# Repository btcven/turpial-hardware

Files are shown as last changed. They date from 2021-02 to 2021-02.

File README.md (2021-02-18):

# Turpial Hardware

Source files for Turpial hardware, designed using KiCAD v5.

## License

Copyright (C) 2021 Locha Mesh Developers

Licensed under the OHL-W-v2 Open Hardware license.

See [LICENSE](./LICENSE) for more information.

## The PCB Stack

According to the recomendations of Texas Instruments the stack will be a 4 layers sandwitch containing:

table-stack

### Layers, view and dimensions
section-stack

### Vias, view and dimensions

section-vias

## Plugins and Tools

### Required

#### RF Tools _KICAD PLUGIN_
    URL: https://github.com/easyw/RF-tools-KiCAD

####  Teardrops
    URL: https://github.com/NilujePerchut/kicad_scripts

### Optionals

#### INTERACTIVE BOM _KICAD PLUGIN_
    Description: Generate an interactive html Bill Of Materials (BOM)
    URL: https://github.com/openscopeproject/InteractiveHtmlBom
    
#### GRAPHICAL SYMBOL GENERATOR (KiSymGen) _KICAD PLUGIN_
    Description: KiSymGen is a graphical symbol generator which makes this process visual and less painful.
    URL: https://github.com/pixellon/imgui
    
#### library.io _ONLINE_TOOL_
    Description: Instantly generate PCB packages by entering a few dimensions from a data sheet.
    URL: https://library.io/

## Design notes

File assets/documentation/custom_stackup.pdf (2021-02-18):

| Layer Name | Usage | Copper Weight (oz) | Copper Thickness ( mils ) | Dielectric Thickness ( mils ) | Single/Diff pair (ohm) | | Tolorance | Single Width (mils) | Diff (90) width / Space(mil) | Diff (100) width / Space(mil)
| | Solder Mask | | 1
1 | TOP | Signal | 1 | 1.35 | | 50/90/100 | +/- | 10% | 6 | 8/5 | 8/7.5
| | Substrate | | | 7
2 | GND | Plane | 1 | 1.35
| | Substrate | | | 42
3 | PWR | Plane | 1 | 1.35
| | Substrate | | | 7
4 | BOTTOM | Signal | 1 | 1.35 | | 50/90/100 | +/- | 10% | 6 | 8/5 | 8/7.5
| | Solder Mask | | 1

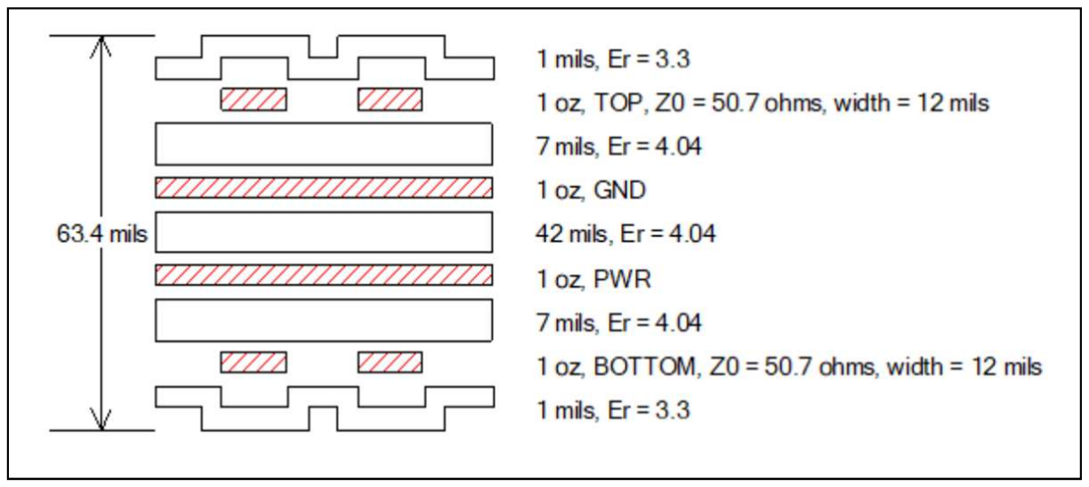
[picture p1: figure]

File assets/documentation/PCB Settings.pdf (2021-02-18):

# PCB Settings

Parámetros

Alto (H) | 156 | mm
Ancho (L) | 120 | mm
Grosor | 1,60 | mm
Nº Capas | 4 | --
Material | FR-4 tg170 | --
Vias | Tenting Vias | --
Surface finish | Immersion Gold | --
Immersion Gold Thickness | 1,00 | mils
Drill Size | <= 0,25 | mm

Distribución del stack, impedancia y tolerancias.

Copper
Weight
(oz)

## Copper Thickness ( mils )

## Dielectric Thickness ( mils )

## Single/Diff

| | | | | pair (ohm) | | Tole rance

## Single Width (mils)

## Diff (90) width / Space(mil)

| | | | | | | | | | Diff (100)
| | | | | | | | | | width /
| | | | | | | | | | Space(mil)
| | Solder M ask | | 1
1 | TOP | Signal | 1 | 1.35 | 50/90/100 | +/- | 10% | 6 | 8/5 | 8/7.5
Substrate | 7
2 | G N D | Plane | 1 | 1.35
Substrate | 42
3 | PW R | Plane | 1 | 1.35
Substrate | 7
4 | B OT T OM | Signal | 1 | 1.35 | 50/90/100 | +/- | 10% | 6 | 8/5 | 8/7.5
| | Solder M ask | | 1
Layer Name | Usage

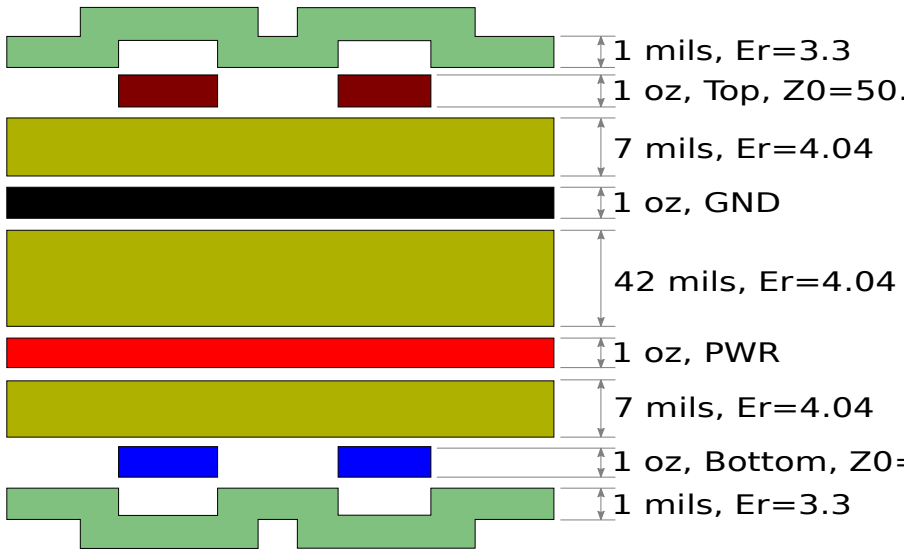
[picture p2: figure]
1 oz, PWR; 1 oz, GND; 42 mils, Er=4.04; 7 mils, Er=4.04; 1 mils, Er=3.3

1 oz, Top, Z0=50.7 Ohms, width=12 mils

1 oz, Bottom, Z0=50.7 Ohms, width=12 mils

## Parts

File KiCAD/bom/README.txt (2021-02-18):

- SM: Surface Mount
- TH:Through Hole.
- DNI: Do Not Include.
- DNM: Include the component in the budget but don't mount it
- DNI-915: Do Not Include for 915MHz

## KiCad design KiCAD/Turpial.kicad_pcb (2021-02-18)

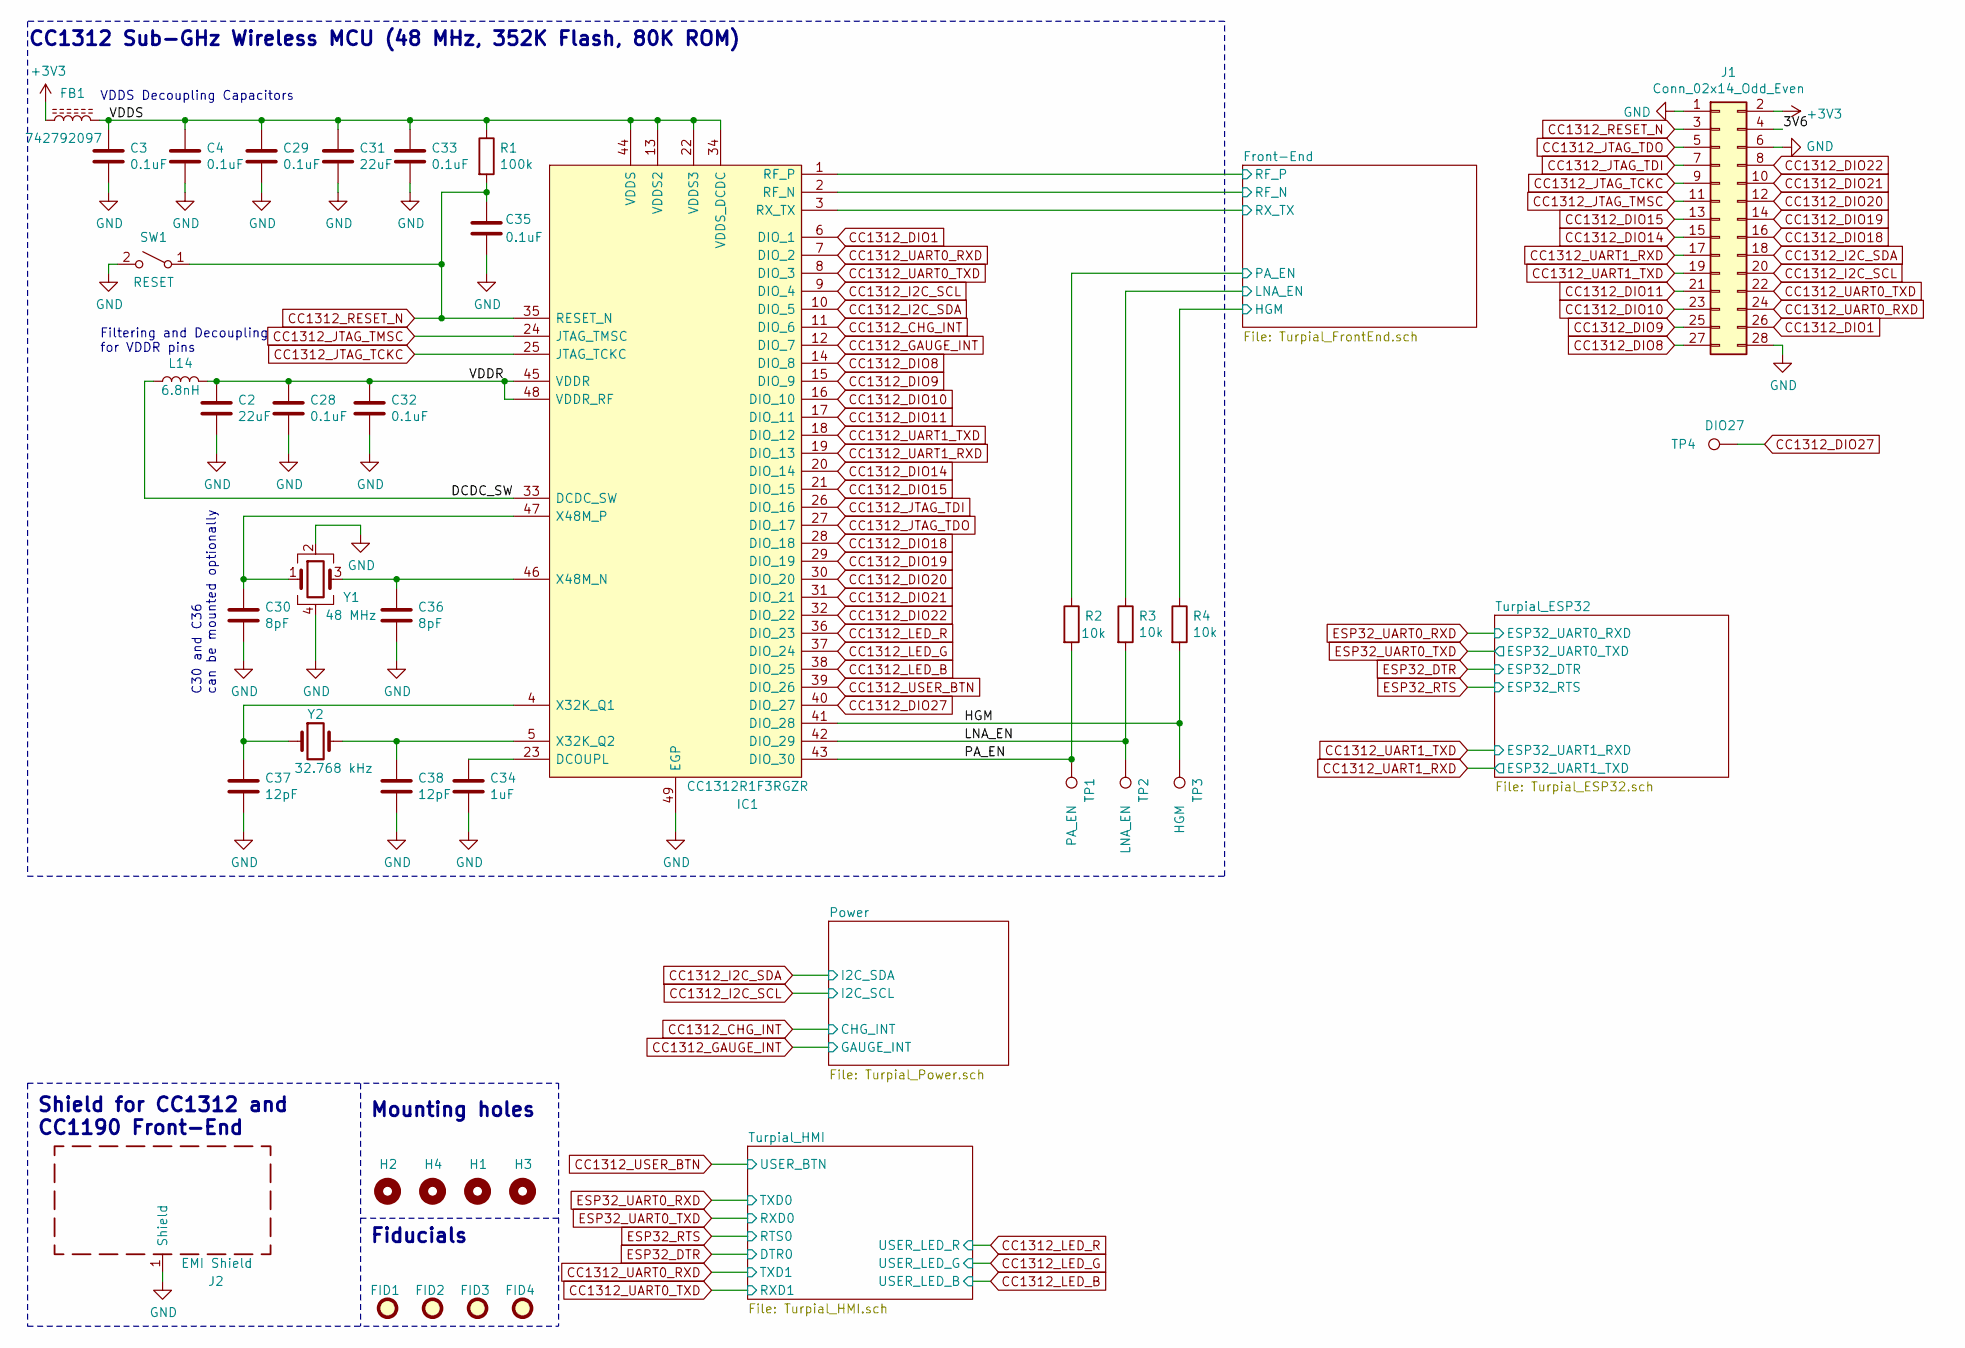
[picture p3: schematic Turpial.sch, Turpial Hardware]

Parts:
C2, C31: 22uF; C_0805_2012Metric; Manufacturer_Part_Number GRM21BR61E226ME44L; Mouser Part Number 81-GRM21BR61E226ME4L
C3, C4, C28, C29, C32, C33, C35: 0.1uF; C_0402_1005Metric; Manufacturer_Part_Number GRM155R61H104KE19D; Mouser Part Number 81-GRM155R61H104KE9D
C30, C36: 8pF; C_0402_1005Metric; Manufacturer_Part_Number GRM0225C1E8R0WA03L; Mouser Part Number 81-GRM0225C1E8R0WA3L
C34: 1uF; C_0402_1005Metric; Manufacturer_Part_Number GRM155R61E105KA12D; Mouser Part Number 81-GRM155R61E105KA2D
C37, C38: 12pF; C_0402_1005Metric; Manufacturer_Part_Number GJM1555C1H120JB01D; Mouser Part Number 81-GJM1555C1H120JB1D
FB1: 742792097; L_0805_2012Metric; Manufacturer_Part_Number 742792097; Mouser Part Number 710-742792097
FID1, FID2, FID3, FID4: Fiducial; Fiducial_1mm_Mask2mm
H1, H2, H3, H4: MountingHole; MountingHole_2.5mm_Pad_Via
IC1: CC1312R1F3RGZR; Texas_S-PVQFN-N48_EP5.15x5.15mm_ThermalVias; Manufacturer_Part_Number CC1312R1F3RGZR; Mouser Part Number 595-CC1312R1F3RGZR
J1: Conn_02x14_Odd_Even; PinHeader_2x14_P2.54mm_Vertical_SMD; Manufacturer_Part_Number 15-91-2140; Mouser Part Number 538-15-91-2140
J2: EMI Shield; SMS-461-F; Manufacturer_Part_Number SMS-461F; Mouser Part Number 861-SMS-461F
L14: 6.8nH; L_0805_2012Metric; Manufacturer_Part_Number MLZ2012N6R8LT000; Mouser Part Number 810-MLZ2012N6R8LT000
R1: 100k; R_0402_1005Metric; Manufacturer_Part_Number RC0402FR-7D100KL; Mouser Part Number 603-RC0402FR-7D100KL
R2, R3, R4: 10k; R_0402_1005Metric; Manufacturer_Part_Number RC0402FR-0710KL; Mouser Part Number 603-RC0402FR-0710KL
SW1: RESET; WS-TASU-Series
TP1: PA_EN; TestPoint_Pad_D1.0mm
TP2: LNA_EN; TestPoint_Pad_D1.0mm
TP3: HGM; TestPoint_Pad_D1.0mm
TP4: DIO27; TestPoint_Pad_D1.0mm
Y1: 48 MHz; Crystal_SMD_2016-4Pin_2.0x1.6mm; Manufacturer_Part_Number NX2016SA-48M-EXS00A-CS08718; Mouser Part Number 344-NX2016SA48S08718
Y2: 32.768 kHz; Crystal_SMD_3215-2Pin_3.2x1.5mm; Manufacturer_Part_Number FC-135 32.7680KA-A3; Mouser Part Number 732-FC135-32.76KAA3

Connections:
+3V3: FB1.1, J1.2; also elsewhere on the board
/3V6: J1.4
/DCDC_SW: IC1.33 (DCDC_SW), L14.1
/Front-End/HGM: R4.1; also elsewhere on the board
/Front-End/LNA_EN: R3.1; also elsewhere on the board
/Front-End/PA_EN: R2.1; also elsewhere on the board
/Front-End/RF_N: IC1.2 (RF_N); also elsewhere on the board
/Front-End/RF_P: IC1.1 (RF_P); also elsewhere on the board
/Front-End/RX_TX: IC1.3 (RX_TX); also elsewhere on the board
/HGM: IC1.41 (DIO_28), R4.2, TP3.1
/LNA_EN: IC1.42 (DIO_29), R3.2, TP2.1
/PA_EN: IC1.43 (DIO_30), R2.2, TP1.1
/VDDR: C2.1, C28.1, C32.1, IC1.45 (VDDR), IC1.48 (VDDR_RF), L14.2
/VDDS: C3.1, C4.1, C29.1, C31.1, C33.1, FB1.2, IC1.13 (VDDS2), IC1.22 (VDDS3), IC1.34 (VDDS_DCDC), IC1.44 (VDDS), R1.1
CC1312_CHG_INT: IC1.11 (DIO_6); also elsewhere on the board
CC1312_DIO1: IC1.6 (DIO_1), J1.26
CC1312_DIO8: IC1.14 (DIO_8), J1.27
CC1312_DIO9: IC1.15 (DIO_9), J1.25
CC1312_DIO10: IC1.16 (DIO_10), J1.23
CC1312_DIO11: IC1.17 (DIO_11), J1.21
CC1312_DIO14: IC1.20 (DIO_14), J1.15
CC1312_DIO15: IC1.21 (DIO_15), J1.13
CC1312_DIO18: IC1.28 (DIO_18), J1.16
CC1312_DIO19: IC1.29 (DIO_19), J1.14
CC1312_DIO20: IC1.30 (DIO_20), J1.12
CC1312_DIO21: IC1.31 (DIO_21), J1.10
CC1312_DIO22: IC1.32 (DIO_22), J1.8
CC1312_DIO27: IC1.40 (DIO_27), TP4.1
CC1312_GAUGE_INT: IC1.12 (DIO_7); also elsewhere on the board
CC1312_I2C_SCL: IC1.9 (DIO_4), J1.20; also elsewhere on the board
CC1312_I2C_SDA: IC1.10 (DIO_5), J1.18; also elsewhere on the board
CC1312_JTAG_TCKC: IC1.25 (JTAG_TCKC), J1.9
CC1312_JTAG_TDI: IC1.26 (DIO_16), J1.7
CC1312_JTAG_TDO: IC1.27 (DIO_17), J1.5
CC1312_JTAG_TMSC: IC1.24 (JTAG_TMSC), J1.11
CC1312_LED_B: IC1.38 (DIO_25); also elsewhere on the board
CC1312_LED_G: IC1.37 (DIO_24); also elsewhere on the board
CC1312_LED_R: IC1.36 (DIO_23); also elsewhere on the board
CC1312_RESET_N: C35.1, IC1.35 (RESET_N), J1.3, R1.2, SW1.1 (A)
CC1312_UART0_RXD: IC1.7 (DIO_2), J1.24; also elsewhere on the board
CC1312_UART0_TXD: IC1.8 (DIO_3), J1.22; also elsewhere on the board
CC1312_UART1_RXD: IC1.19 (DIO_13), J1.17; also elsewhere on the board
CC1312_UART1_TXD: IC1.18 (DIO_12), J1.19; also elsewhere on the board
CC1312_USER_BTN: IC1.39 (DIO_26); also elsewhere on the board
GND: C2.2, C3.2, C4.2, C28.2, C29.2, C30.2, C31.2, C32.2, C33.2, C34.2, C35.2, C36.2, C37.2, C38.2, IC1.49 (EGP), J1.1, J1.6, J1.28, J2.1, SW1.2 (B), Y1.2, Y1.4; also elsewhere on the board
unnamed: C30.1, IC1.47 (X48M_P), Y1.1
unnamed: C34.1, IC1.23 (DCOUPL)
unnamed: C36.1, IC1.46 (X48M_N), Y1.3
unnamed: C37.1, IC1.4 (X32K_Q1), Y2.1
unnamed: C38.1, IC1.5 (X32K_Q2), Y2.2

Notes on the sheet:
VDDS Decoupling Capacitors
Filtering and Decoupling for VDDR pins
C30 and C36 can be mounted optionally
CC1312 Sub-GHz Wireless MCU (48 MHz, 352K Flash, 80K ROM)
Shield for CC1312 and CC1190 Front-End
Fiducials
Mounting holes

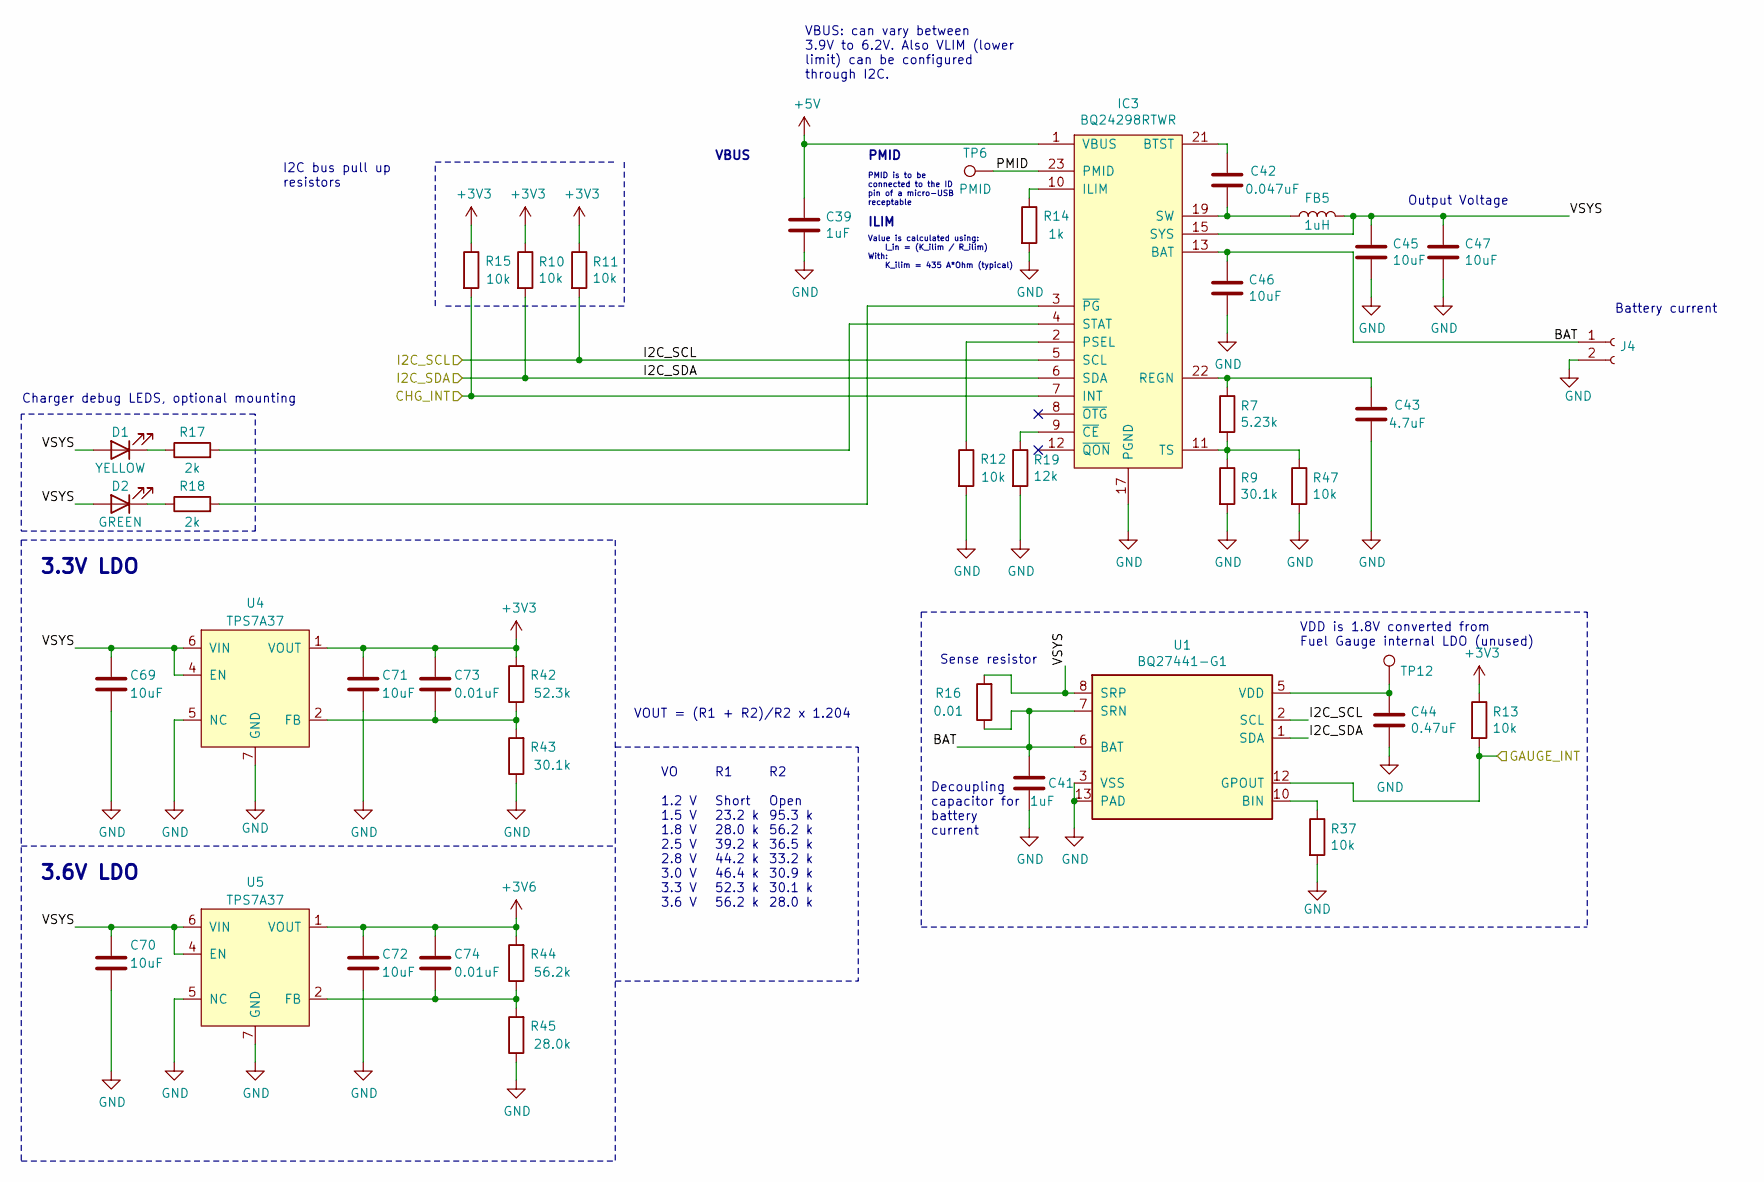
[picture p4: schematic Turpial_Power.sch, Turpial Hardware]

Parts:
C39, C41: 1uF; C_0402_1005Metric; Manufacturer_Part_Number GRM155R61E105KA12D; Mouser Part Number 81-GRM155R61E105KA2D
C42: 0.047uF; C_0402_1005Metric; Manufacturer_Part_Number GRM155R71H473KE14D; Mouser Part Number 81-GRM155R71H473KE4D
C43: 4.7uF; C_0402_1005Metric; Manufacturer_Part_Number GRM155R61A475MEAAD; Mouser Part Number 81-GRM155R61A475MEAD
C44: 0.47uF; C_0402_1005Metric; Manufacturer_Part_Number GRM155R71A474KE01D; Mouser Part Number 81-GRM155R71A474KE1D
C45, C46, C47, C69, C70, C71, C72: 10uF; C_0603_1608Metric; Manufacturer_Part_Number GRM188R61E106MA73J; Mouser Part Number 81-GRM188R61E106MA3J
C73, C74: 0.01uF; C_0603_1608Metric; Manufacturer_Part_Number GRM188R72A103KA01D; Mouser Part Number 81-GRM188R72A103KA1D
D1: YELLOW; LED_0603_1608Metric; Manufacturer_Part_Number LTST-C191KRKT; Mouser Part Number 859-LTST-C191KRKT
D2: GREEN; LED_0603_1608Metric; Manufacturer_Part_Number LTST-C191KGKT; Mouser Part Number 859-LTST-C191KGKT
FB5: 1uH; L_0805_2012Metric; Manufacturer_Part_Number DFE201210S-1R0M=P2; Mouser Part Number 81-DFE201210S-1R0MP2
IC3: BQ24298RTWR; Texas_S-PWQFN-N24_EP2.7x2.7mm_ThermalVias; Manufacturer_Part_Number BQ24298RTWR; Mouser Part Number 595-BQ24298RTWR
J4: Conn_01x02_Female; PinHeader_1x02_P2.54mm_Vertical
R7: 5.23k; R_0402_1005Metric; Manufacturer_Part_Number RC0402FR-075K23L; Mouser Part Number 603-RC0402FR-075K23L
R9, R43: 30.1k; R_0603_1608Metric; Manufacturer_Part_Number RC0603FR-0730K1L; Mouser Part Number 603-RC0603FR-0730K1L
R10, R11, R12, R13, R15, R37, R47: 10k; R_0402_1005Metric; Manufacturer_Part_Number RC0402FR-0710KL; Mouser Part Number 603-RC0402FR-0710KL
R14: 1k; R_0603_1608Metric; Manufacturer_Part_Number RC0603FR-071KL; Mouser Part Number 603-RC0603FR-071KL
R16: 0.01; R_0603_1608Metric; Manufacturer_Part_Number MFC0603-R01FT5; Mouser Part Number 756-MFC0603-R01FT5
R17, R18: 2k; R_0402_1005Metric; Manufacturer_Part_Number RC0402FR-072KL; Mouser Part Number 603-RC0402FR-072KL
R19: 12k; R_0402_1005Metric; Manufacturer_Part_Number RC0402FR-0712KL; Mouser Part Number 603-RC0402FR-0712KL
R42: 52.3k; R_0603_1608Metric; Manufacturer_Part_Number RC0603FR-0752K3L; Mouser Part Number 603-RC0603FR-0752K3L
R44: 56.2k; R_0603_1608Metric; Manufacturer_Part_Number RC0603FR-0756K2L; Mouser Part Number 603-RC0603FR-0756K2L
R45: 28.0k; R_0603_1608Metric; Manufacturer_Part_Number RC0603FR-0728KL; Mouser Part Number 603-RC0603FR-0728KL
TP6: PMID; TestPoint_Pad_D1.0mm
TP12: TestPoint; TestPoint_Pad_D1.0mm
U1: BQ27441-G1; Texas_S-PDSO-N12; Manufacturer_Part_Number BQ27441DRZT-G1A; Mouser Part Number 595-BQ27441DRZT-G1A
U4, U5: TPS7A37; Manufacturer_Part_Number TPS7A3701DRVR; Mouser Part Number 595-TPS7A3701DRVR

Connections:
+3V3: C71.1, C73.1, R10.1, R11.1, R13.1, R15.1, R42.2, U4.1 (VOUT); also elsewhere on the board
+3V6: C72.1, C74.1, R44.2, U5.1 (VOUT); also elsewhere on the board
+5V: C39.1, IC3.1 (VBUS), IC3.24 (VBUS); also elsewhere on the board
/Power/BAT: C41.1, C46.2, IC3.13 (BAT), IC3.14 (BAT), J4.1, R16.1, U1.6 (BAT), U1.7 (SRN)
/Power/PMID: IC3.23 (PMID), TP6.1
/Power/VSYS: C45.1, C47.1, C69.1, C70.1, D1.2 (A), D2.2 (A), FB5.2, IC3.15 (SYS), IC3.16 (SYS), R16.2, U1.8 (SRP), U4.4 (EN), U4.6 (VIN), U5.4 (EN), U5.6 (VIN)
CC1312_CHG_INT: IC3.7 (INT), R15.2; also elsewhere on the board
CC1312_GAUGE_INT: R13.2, U1.12 (GPOUT); also elsewhere on the board
CC1312_I2C_SCL: IC3.5 (SCL), R11.2, U1.2 (SCL); also elsewhere on the board
CC1312_I2C_SDA: IC3.6 (SDA), R10.2, U1.1 (SDA); also elsewhere on the board
GND: C39.2, C41.2, C43.2, C44.2, C45.2, C46.1, C47.2, C69.2, C70.2, C71.2, C72.2, IC3.17 (PGND), IC3.18 (PGND), IC3.25 (GND), J4.2, R9.2, R12.2, R14.2, R19.2, R37.2, R43.1, R45.1, R47.2, U1.3 (VSS), U1.13 (PAD), U4.3 (GND), U4.5 (NC), U4.7 (GND), U5.3 (GND), U5.5 (NC), U5.7 (GND); also elsewhere on the board
unnamed: C42.1, FB5.1, IC3.19 (SW), IC3.20 (SW)
unnamed: C42.2, IC3.21 (BTST)
unnamed: C43.1, IC3.22 (REGN), R7.1
unnamed: C44.1, TP12.1, U1.5 (VDD)
unnamed: C73.2, R42.1, R43.2, U4.2 (FB)
unnamed: C74.2, R44.1, R45.2, U5.2 (FB)
unnamed: D1.1 (K), R17.1
unnamed: D2.1 (K), R18.1
unnamed: IC3.2 (PSEL), R12.1
unnamed: IC3.3 (~PG), R18.2
unnamed: IC3.4 (STAT), R17.2
unnamed: IC3.9 (~CE), R19.1
unnamed: IC3.10 (ILIM), R14.1
unnamed: IC3.11 (TS), R7.2, R9.1, R47.1
unnamed: R37.1, U1.10 (BIN)

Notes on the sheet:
VBUS: can vary between 3.9V to 6.2V. Also VLIM (lower limit) can be configured through I2C.
ILIM
3.3V LDO
3.6V LDO
VOUT = (R1 + R2)/R2 x 1.204
R1 Short 23.2 k 28.0 k 39.2 k 44.2 k 46.4 k 52.3 k 56.2 k
R2 Open 95.3 k 56.2 k 36.5 k 33.2 k 30.9 k 30.1 k 28.0 k
Charger debug LEDS, optional mounting
VDD is 1.8V converted from Fuel Gauge internal LDO (unused)
Sense resistor
Decoupling capacitor for battery current
I2C bus pull up resistors
Output Voltage
PMID
VO 1.2 V 1.5 V 1.8 V 2.5 V 2.8 V 3.0 V 3.3 V 3.6 V
Battery current
Value is calculated using: I_in = (K_ilim / R_ilim) With: K_ilim = 435 A*Ohm (typical)
VBUS
PMID is to be connected to the ID pin of a micro-USB receptable

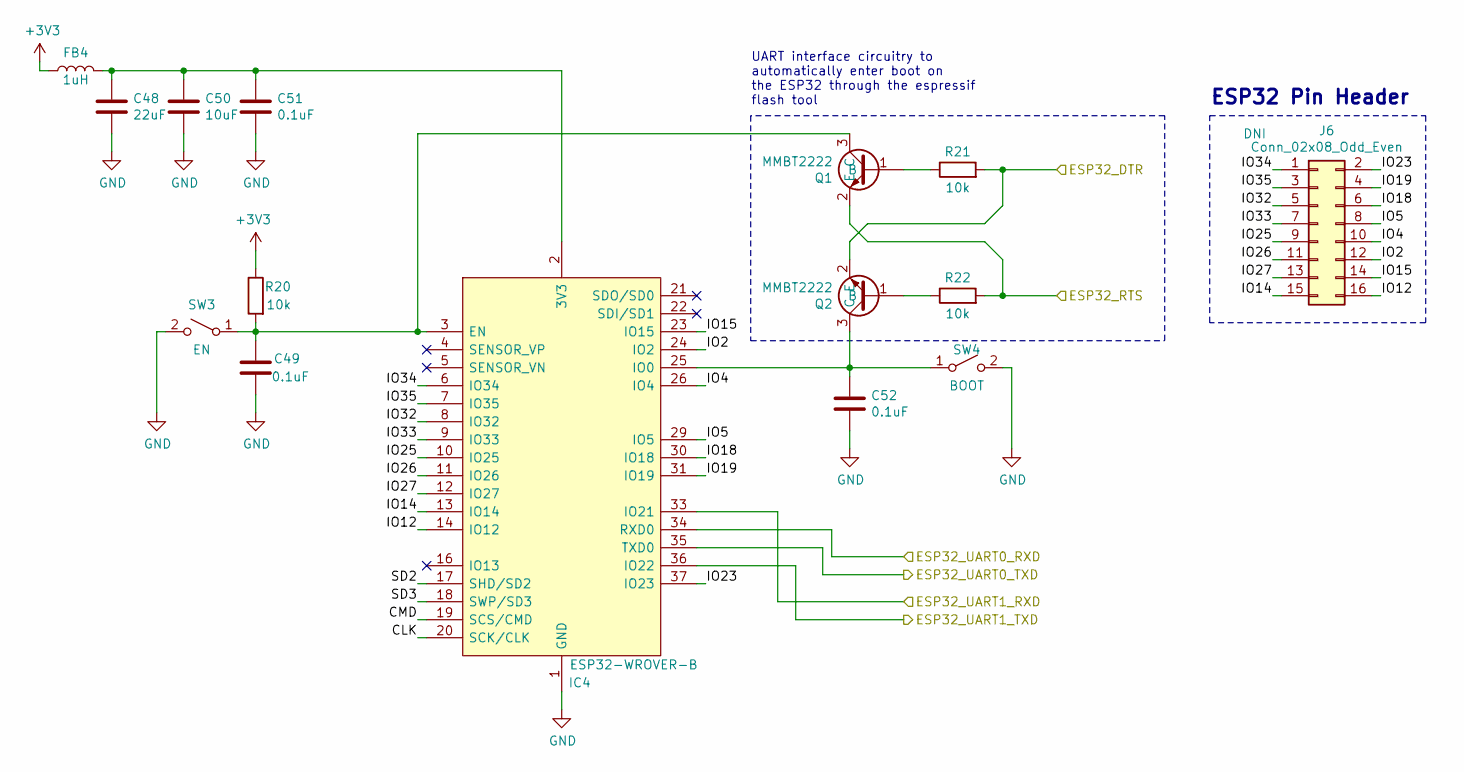
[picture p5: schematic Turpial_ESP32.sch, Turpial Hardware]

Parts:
C48: 22uF; C_0805_2012Metric; Manufacturer_Part_Number GRM21BR61E226ME44L; Mouser Part Number 81-GRM21BR61E226ME4L
C49, C51, C52: 0.1uF; C_0402_1005Metric; Manufacturer_Part_Number GRM155R61H104KE19D; Mouser Part Number 81-GRM155R61H104KE9D
C50: 10uF; C_0603_1608Metric; Manufacturer_Part_Number GRM188R61E106MA73J; Mouser Part Number 81-GRM188R61E106MA3J
FB4: 1uH; L_0805_2012Metric; Manufacturer_Part_Number DFE201210S-1R0M=P2; Mouser Part Number 81-DFE201210S-1R0MP2
IC4: ESP32-WROVER-B; Manufacturer_Part_Number ESP32-WROVER-B(M213DH3264PH3Q0); Mouser Part Number 356-ESP32-WROVER-B
J6: Conn_02x08_Odd_Even; PinHeader_2x08_P2.54mm_Vertical_SMD; Manufacturer_Part_Number 71308-5408; Mouser Part Number 538-71308-5408
Q1, Q2: MMBT2222; SOT-23; Manufacturer_Part_Number MMBT2222ALT1G; Mouser Part Number 863-MMBT2222ALT1G
R20, R21, R22: 10k; R_0402_1005Metric; Manufacturer_Part_Number RC0402FR-0710KL; Mouser Part Number 603-RC0402FR-0710KL
SW3: EN; WS-TASU-Series
SW4: BOOT; WS-TASU-Series

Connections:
+3V3: FB4.1, R20.1; also elsewhere on the board
/Turpial_ESP32/CLK: IC4.20 (SCK/CLK)
/Turpial_ESP32/CMD: IC4.19 (SCS/CMD)
/Turpial_ESP32/IO2: IC4.24 (IO2), J6.12
/Turpial_ESP32/IO4: IC4.26 (IO4), J6.10
/Turpial_ESP32/IO5: IC4.29 (IO5), J6.8
/Turpial_ESP32/IO12: IC4.14 (IO12), J6.16
/Turpial_ESP32/IO14: IC4.13 (IO14), J6.15
/Turpial_ESP32/IO15: IC4.23 (IO15), J6.14
/Turpial_ESP32/IO18: IC4.30 (IO18), J6.6
/Turpial_ESP32/IO19: IC4.31 (IO19), J6.4
/Turpial_ESP32/IO23: IC4.37 (IO23), J6.2
/Turpial_ESP32/IO25: IC4.10 (IO25), J6.9
/Turpial_ESP32/IO26: IC4.11 (IO26), J6.11
/Turpial_ESP32/IO27: IC4.12 (IO27), J6.13
/Turpial_ESP32/IO32: IC4.8 (IO32), J6.5
/Turpial_ESP32/IO33: IC4.9 (IO33), J6.7
/Turpial_ESP32/IO34: IC4.6 (IO34), J6.1
/Turpial_ESP32/IO35: IC4.7 (IO35), J6.3
/Turpial_ESP32/SD2: IC4.17 (SHD/SD2)
/Turpial_ESP32/SD3: IC4.18 (SWP/SD3)
CC1312_UART1_RXD: IC4.36 (IO22); also elsewhere on the board
CC1312_UART1_TXD: IC4.33 (IO21); also elsewhere on the board
ESP32_DTR: Q2.2 (E), R21.2; also elsewhere on the board
ESP32_RTS: Q1.2 (E), R22.2; also elsewhere on the board
ESP32_UART0_RXD: IC4.34 (RXD0); also elsewhere on the board
ESP32_UART0_TXD: IC4.35 (TXD0); also elsewhere on the board
GND: C48.2, C49.2, C50.2, C51.2, C52.2, IC4.1 (GND), IC4.15 (GND), IC4.38 (GND), IC4.39 (GND), SW3.2 (B), SW4.2 (B); also elsewhere on the board
unnamed: C48.1, C50.1, C51.1, FB4.2, IC4.2 (3V3)
unnamed: C49.1, IC4.3 (EN), Q1.3 (C), R20.2, SW3.1 (A)
unnamed: C52.1, IC4.25 (IO0), Q2.3 (C), SW4.1 (A)
unnamed: Q1.1 (B), R21.1
unnamed: Q2.1 (B), R22.1

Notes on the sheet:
UART interface circuitry to automatically enter boot on the ESP32 through the espressif flash tool
ESP32 Pin Header

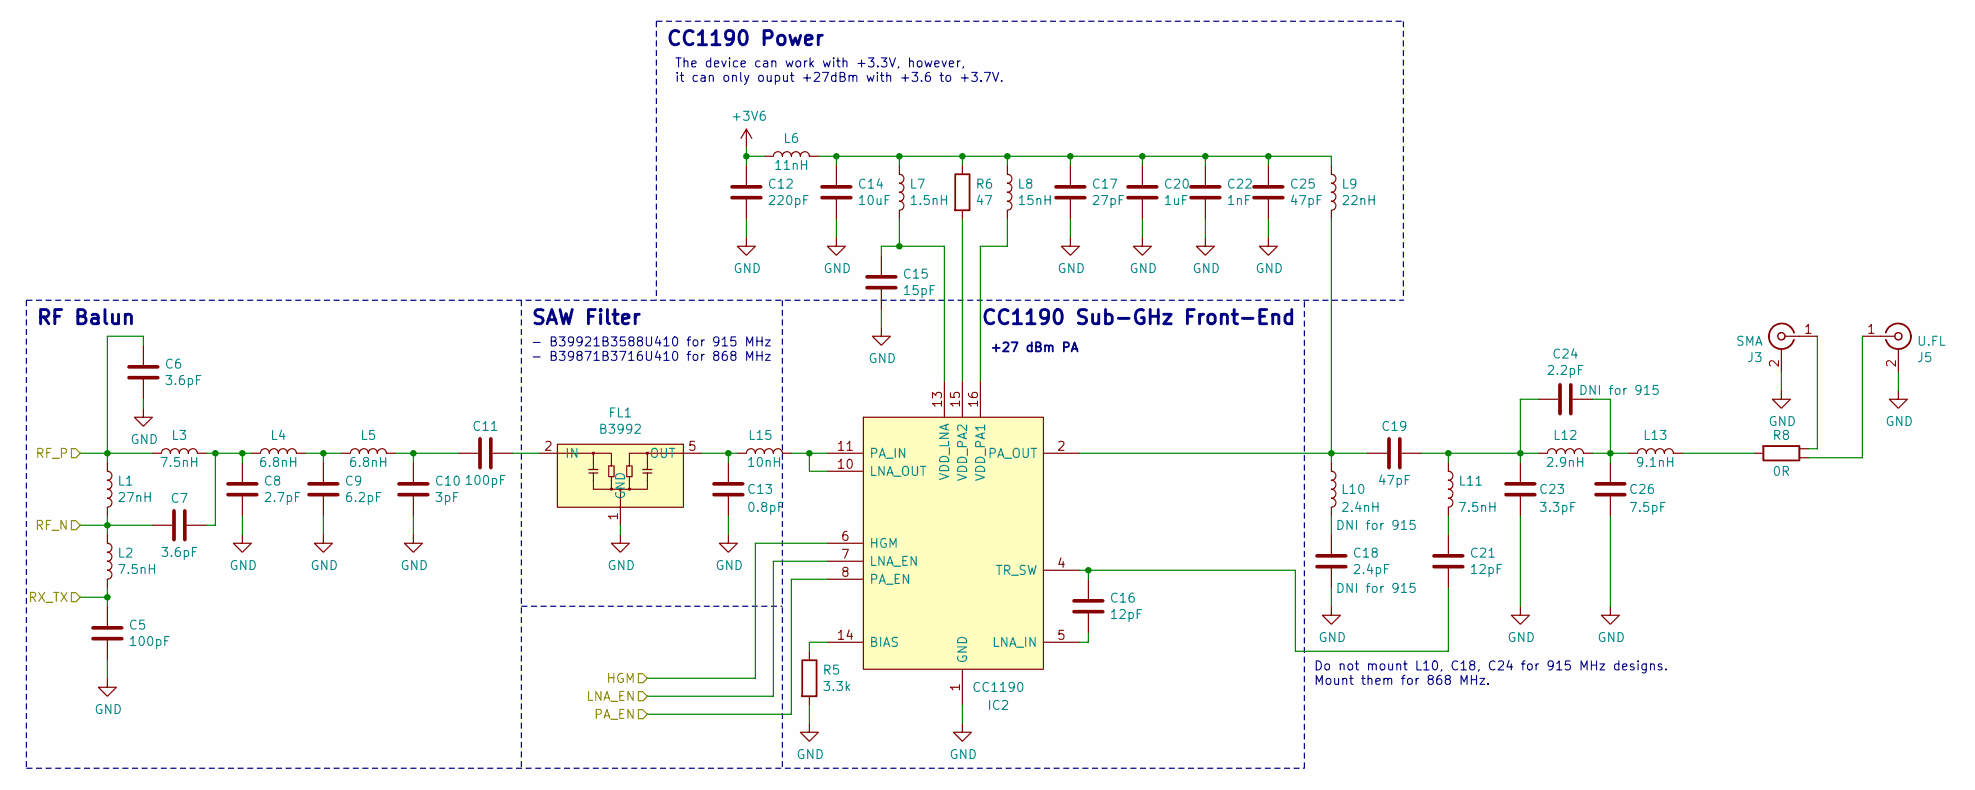
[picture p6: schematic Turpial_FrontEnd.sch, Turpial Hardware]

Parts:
C5, C11: 100pF; C_0402_1005Metric; Manufacturer_Part_Number GCM1555C1H101JA16D; Mouser Part Number 81-GCM1555C1H101JA6D
C6, C7: 3.6pF; C_0402_1005Metric; Manufacturer_Part_Number GJM1555C1H3R6CB01D; Mouser Part Number 81-GJM1555C1H3R6CB1D
C8: 2.7pF; C_0402_1005Metric; Manufacturer_Part_Number GJM1555C1H2R7CB01D; Mouser Part Number 81-GJM1555C1H2R7CB1D
C9: 6.2pF; C_0402_1005Metric; Manufacturer_Part_Number GJM1555C1H6R2CB01D; Mouser Part Number 81-GJM1555C1H6R2CB01
C10: 3pF; C_0402_1005Metric; Manufacturer_Part_Number GJM1555C1H3R0CB01D; Mouser Part Number 81-GJM1555C1H3R0CB1D
C12: 220pF; C_0402_1005Metric; Manufacturer_Part_Number GCM1555C1H221JA16D; Mouser Part Number 81-GCM1555C1H221J16D
C13: 0.8pF; C_0402_1005Metric; Manufacturer_Part_Number GJM1555C1HR80DB01J; Mouser Part Number 81-GJM1555C1HR80DB1J
C14: 10uF; C_0603_1608Metric; Manufacturer_Part_Number GRM188R61E106MA73J; Mouser Part Number 81-GRM188R61E106MA3J
C15: 15pF; C_0402_1005Metric; Manufacturer_Part_Number GJM1555C1H150JB01J; Mouser Part Number 81-GJM1555C1H150JB1J
C16, C21: 12pF; C_0402_1005Metric; Manufacturer_Part_Number GJM1555C1H120JB01D; Mouser Part Number 81-GJM1555C1H120JB1D
C17: 27pF; C_0402_1005Metric; Manufacturer_Part_Number GJM1555C1H270JB01D; Mouser Part Number 81-GJM1555C1H270JB1D
C18: 2.4pF; C_0402_1005Metric; Manufacturer_Part_Number GJM1555C1H2R4CB01D; Mouser Part Number 81-GJM1555C1H2R4CB1D
C19, C25: 47pF; C_0402_1005Metric; Manufacturer_Part_Number GJM1555C1H470JB01J; Mouser Part Number 81-GJM1555C1H470JB1J
C20: 1uF; C_0402_1005Metric; Manufacturer_Part_Number GRM155R61E105KA12D; Mouser Part Number 81-GRM155R61E105KA2D
C22: 1nF; C_0402_1005Metric; Manufacturer_Part_Number GCM155R71H102KA37D; Mouser Part Number 81-GCM155R71H102KA7D
C23: 3.3pF; C_0402_1005Metric; Manufacturer_Part_Number GJM1555C1H3R3CB01D; Mouser Part Number 81-GJM1555C1H3R3CB1D
C24: 2.2pF; C_0402_1005Metric; Manufacturer_Part_Number GJM1555C1H2R2CB01D; Mouser Part Number 81-GJM1555C1H2R2CB1D
C26: 7.5pF; C_0402_1005Metric; Manufacturer_Part_Number GJM1555C1H7R5CB01D; Mouser Part Number 81-GJM1555C1H7R5CB01
FL1: B3992; FIL_B39921B3588U410; Manufacturer_Part_Number B39921B3588U410; Mouser Part Number 871-B39921B3588U410
IC2: CC1190; Texas_S-PVQFN-N16_EP2.7x2.7mm_ThermalVias; Manufacturer_Part_Number CC1190RGVR; Mouser Part Number 595-CC1190RGVR
J3: SMA; SMA_EDGEMOUNT
J5: U.FL; U.FL_Linx_CONUFL001-SMD-T; Manufacturer_Part_Number CONUFL001-SMD-T; Mouser Part Number 712-CONUFL001-SMD-T
L1: 27nH; L_0402_1005Metric; Manufacturer_Part_Number LQG15HS27NJ02D; Mouser Part Number 81-LQG15HS27NJ02D
L2, L3, L11: 7.5nH; L_0402_1005Metric; Manufacturer_Part_Number LQW15AN7N5G00D; Mouser Part Number 81-LQW15AN7N5G00D
L4, L5: 6.8nH; L_0402_1005Metric; Manufacturer_Part_Number LQG15HS6N8J02D; Mouser Part Number 81-LQG15HS6N8J02D
L6: 11nH; L_0402_1005Metric; Manufacturer_Part_Number LQW15AN11NJ00D; Mouser Part Number 81-LQW15AN11NJ00D
L7: 1.5nH; L_0402_1005Metric; Manufacturer_Part_Number LQG15HS1N5S02D; Mouser Part Number 81-LQG15HS1N5S02D
L8: 15nH; L_0402_1005Metric; Manufacturer_Part_Number LQW15AN15NJ00D; Mouser Part Number 81-LQW15AN15NJ00D
L9: 22nH; L_0603_1608Metric; Manufacturer_Part_Number LQW18AN22NJ10D; Mouser Part Number 81-LQW18AN22NJ10D
L10: 2.4nH; L_0402_1005Metric
L12: 2.9nH; L_0402_1005Metric; Manufacturer_Part_Number LQW15AN2N9C00D; Mouser Part Number 81-LQW15AN2N9C00D
L13: 9.1nH; L_0402_1005Metric; Manufacturer_Part_Number LQW15AN9N1G00D; Mouser Part Number 81-LQW15AN9N1G00D
L15: 10nH; L_0402_1005Metric; Manufacturer_Part_Number LQW15AN10NJ00D; Mouser Part Number 81-LQW15AN10NJ00D
R5: 3.3k; R_0402_1005Metric; Manufacturer_Part_Number RC0402FR-7D3K3L; Mouser Part Number 603-RC0402FR-7D3K3L
R6: 47; R_0402_1005Metric; Manufacturer_Part_Number RC0402FR-0747RL; Mouser Part Number 603-RC0402FR-0747RL
R8: 0R; YR_0402

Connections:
+3V6: C12.1, L6.1; also elsewhere on the board
/Front-End/HGM: IC2.6 (HGM); also elsewhere on the board
/Front-End/LNA_EN: IC2.7 (LNA_EN); also elsewhere on the board
/Front-End/PA_EN: IC2.8 (PA_EN); also elsewhere on the board
/Front-End/RF_N: C7.2, L1.2, L2.1; also elsewhere on the board
/Front-End/RF_P: C6.2, L1.1, L3.1; also elsewhere on the board
/Front-End/RX_TX: C5.1, L2.2; also elsewhere on the board
GND: C5.2, C6.1, C8.2, C9.2, C10.2, C12.2, C13.2, C14.2, C15.2, C17.2, C18.2, C20.2, C22.2, C23.2, C25.2, C26.2, FL1.1 (GND), FL1.3 (GND), FL1.4 (GND), FL1.6 (GND), IC2.1 (GND), IC2.3 (GND), IC2.9 (GND), IC2.12 (GND), IC2.17 (GND), J3.2 (Ext), J5.2 (Ext), R5.2; also elsewhere on the board
unnamed: C7.1, C8.1, L3.2, L4.1
unnamed: C9.1, L4.2, L5.1
unnamed: C10.1, C11.2, L5.2
unnamed: C11.1, FL1.2 (IN)
unnamed: C13.1, FL1.5 (OUT), L15.1
unnamed: C14.1, C17.1, C20.1, C22.1, C25.1, L6.2, L7.1, L8.1, L9.1, R6.1
unnamed: C15.1, IC2.13 (VDD_LNA), L7.2
unnamed: C16.1, C21.2, IC2.4 (TR_SW)
unnamed: C16.2, IC2.5 (LNA_IN)
unnamed: C18.1, L10.2
unnamed: C19.1, C23.1, C24.2, L11.1, L12.1
unnamed: C19.2, IC2.2 (PA_OUT), L9.2, L10.1
unnamed: C21.1, L11.2
unnamed: C24.1, C26.1, L12.2, L13.1
unnamed: IC2.10 (LNA_OUT), IC2.11 (PA_IN), L15.2
unnamed: IC2.14 (BIAS), R5.1
unnamed: IC2.15 (VDD_PA2), R6.2
unnamed: IC2.16 (VDD_PA1), L8.2
unnamed: J3.1 (In), R8.2
unnamed: J5.1 (In), R8.3
unnamed: L13.2, R8.1

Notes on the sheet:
Do not mount L10, C18, C24 for 915 MHz designs. Mount them for 868 MHz.
RF Balun
SAW Filter
- B39921B3588U410 for 915 MHz - B39871B3716U410 for 868 MHz
CC1190 Sub-GHz Front-End
+27 dBm PA
CC1190 Power
The device can work with +3.3V, however, it can only ouput +27dBm with +3.6 to +3.7V.

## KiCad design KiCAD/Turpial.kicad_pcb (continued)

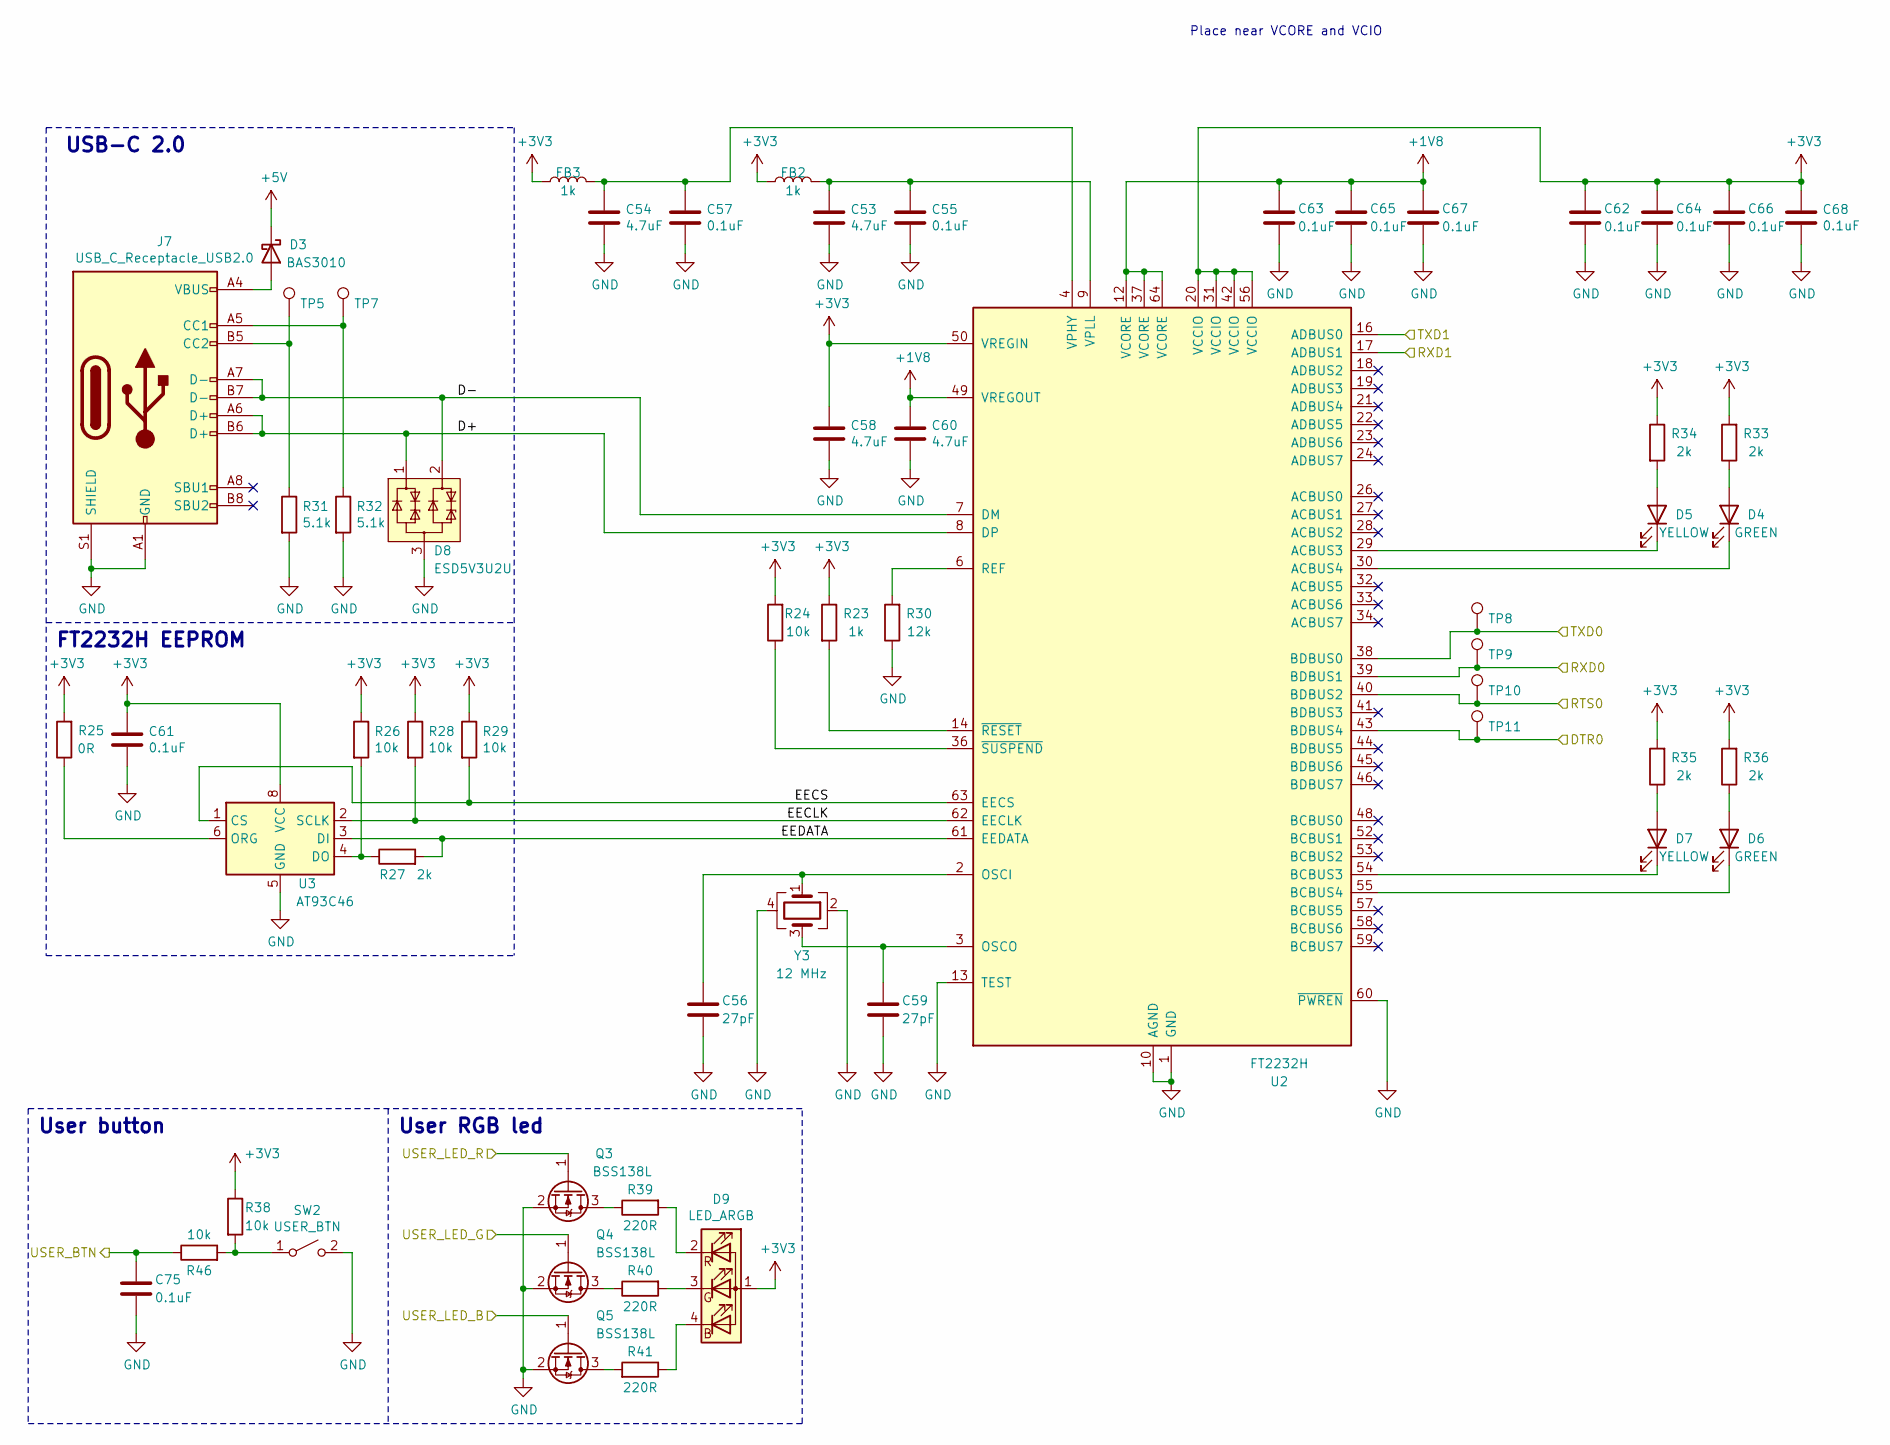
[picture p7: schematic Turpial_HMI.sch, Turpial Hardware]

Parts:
C53, C54, C58, C60: 4.7uF; C_0402_1005Metric; Manufacturer_Part_Number GRM155R61A475MEAAD; Mouser Part Number 81-GRM155R61A475MEAD
C55, C57, C61, C62, C63, C64, C65, C66, C67, C68, C75: 0.1uF; C_0402_1005Metric; Manufacturer_Part_Number GRM155R61H104KE19D; Mouser Part Number 81-GRM155R61H104KE9D
C56, C59: 27pF; C_0402_1005Metric; Manufacturer_Part_Number GJM1555C1H270JB01D; Mouser Part Number 81-GJM1555C1H270JB1D
D3: BAS3010; D_SOD-323; Manufacturer_Part_Number BAS3010A03WE6327HTSA1; Mouser Part Number 726-BAS3010A-03WE6
D4, D6: GREEN; LED_0603_1608Metric; Manufacturer_Part_Number LTST-C191KSKT; Mouser Part Number 859-LTST-C191KSKT
D5, D7: YELLOW; LED_0603_1608Metric; Manufacturer_Part_Number LTST-C191KGKT; Mouser Part Number 859-LTST-C191KGKT
D8: ESD5V3U2U; SOT-723; Manufacturer_Part_Number ESD5V3U2U03FH6327XTSA1; Mouser Part Number 726-5V3U2U03FH6327XT
D9: LED_ARGB; LED_HSMFC118; Manufacturer_Part_Number HSMF-C118; Mouser Part Number 630-HSMF-C118
FB2, FB3: 1k; L_0603_1608Metric; Manufacturer_Part_Number BLM18KG102SN1D; Mouser Part Number 81-BLM18KG102SN1D
J7: USB_C_Receptacle_USB2.0; CONN-USBC_SS-52400-003
Q3, Q4, Q5: BSS138L; SOT-23; Manufacturer_Part_Number BSS138L; Mouser Part Number 512-BSS138L
R23: 1k; R_0603_1608Metric; Manufacturer_Part_Number RC0603FR-071KL; Mouser Part Number 603-RC0603FR-071KL
R24, R26, R28, R29, R38, R46: 10k; R_0402_1005Metric; Manufacturer_Part_Number RC0402FR-0710KL; Mouser Part Number 603-RC0402FR-0710KL
R25: 0R; R_0402_1005Metric; Manufacturer_Part_Number RC0402JR-070RL; Mouser Part Number 603-RC0402JR-070RL
R27, R33, R34, R35, R36: 2k; R_0402_1005Metric; Manufacturer_Part_Number RC0402FR-072KL; Mouser Part Number 603-RC0402FR-072KL
R30: 12k; R_0402_1005Metric; Manufacturer_Part_Number RC0402FR-0712KL; Mouser Part Number 603-RC0402FR-0712KL
R31, R32: 5.1k; R_0402_1005Metric; Manufacturer_Part_Number RC0402FR-075K1L; Mouser Part Number 603-RC0402FR-075K1L
R39, R40, R41: 220R; R_0603_1608Metric; Manufacturer_Part_Number CRCW0603220RJNEAC; Mouser Part Number 71-CRCW0603220RJNEAC
SW2: USER_BTN; WS-TASU-Series
TP5: CC2; TestPoint_Pad_D1.0mm
TP7: CC1; TestPoint_Pad_D1.0mm
TP8: RXD0; TestPoint_Pad_D1.0mm
TP9: TXD0; TestPoint_Pad_D1.0mm
TP10: RTS0; TestPoint_Pad_D1.0mm
TP11: DTR0; TestPoint_Pad_D1.0mm
U2: FT2232H; LQFP-64_10x10mm_P0.5mm; Manufacturer_Part_Number FT2232HL-TRAY; Mouser Part Number 895-FT2232HL-TRAY
U3: AT93C46; SOIC-8_3.9x4.9mm_P1.27mm; Manufacturer_Part_Number AT93C46DN-SH-T; Mouser Part Number 556-A93C46DNSHT
Y3: 12 MHz; Crystal_SMD_3225-4Pin_3.2x2.5mm; Manufacturer_Part_Number ECS-120-12-33-AEN-TR; Mouser Part Number 520-120-12-33-AENT

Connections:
+1V8: C60.1, C63.1, C65.1, C67.1, U2.12 (VCORE), U2.37 (VCORE), U2.49 (VREGOUT), U2.64 (VCORE)
+3V3: C58.1, C61.1, C62.1, C64.1, C66.1, C68.1, D9.1 (A), FB2.1, FB3.1, R23.1, R24.2, R25.2, R26.1, R28.1, R29.1, R33.2, R34.1, R35.2, R36.2, R38.1, U2.20 (VCCIO), U2.31 (VCCIO), U2.42 (VCCIO), U2.50 (VREGIN), U2.56 (VCCIO), U3.8 (VCC); also elsewhere on the board
+5V: D3.1 (K); also elsewhere on the board
/Turpial_HMI/D+: D8.1, J7.A6 (D+), J7.B6 (D+), U2.8 (DP)
/Turpial_HMI/D-: D8.2, J7.A7 (D-), J7.B7 (D-), U2.7 (DM)
/Turpial_HMI/EECLK: R28.2, U2.62 (EECLK), U3.2 (SCLK)
/Turpial_HMI/EECS: R29.2, U2.63 (EECS), U3.1 (CS)
/Turpial_HMI/EEDATA: R27.2, U2.61 (EEDATA), U3.3 (DI)
CC1312_LED_B: Q5.1 (G); also elsewhere on the board
CC1312_LED_G: Q4.1 (G); also elsewhere on the board
CC1312_LED_R: Q3.1 (G); also elsewhere on the board
CC1312_UART0_RXD: U2.16 (ADBUS0); also elsewhere on the board
CC1312_UART0_TXD: U2.17 (ADBUS1); also elsewhere on the board
CC1312_USER_BTN: C75.1, R46.1; also elsewhere on the board
ESP32_DTR: TP11.1, U2.43 (BDBUS4); also elsewhere on the board
ESP32_RTS: TP10.1, U2.40 (BDBUS2); also elsewhere on the board
ESP32_UART0_RXD: TP8.1, U2.38 (BDBUS0); also elsewhere on the board
ESP32_UART0_TXD: TP9.1, U2.39 (BDBUS1); also elsewhere on the board
GND: C53.2, C54.2, C55.2, C56.2, C57.2, C58.2, C59.2, C60.2, C61.2, C62.2, C63.2, C64.2, C65.2, C66.2, C67.2, C68.2, C75.2, D8.3, J7.A1 (GND), J7.A12 (GND), J7.B1 (GND), J7.B12 (GND), J7.S1 (SHIELD), Q3.2 (S), Q4.2 (S), Q5.2 (S), R30.1, R31.2, R32.2, SW2.2 (B), U2.1 (GND), U2.5 (GND), U2.10 (AGND), U2.11 (GND), U2.13 (TEST), U2.15 (GND), U2.25 (GND), U2.35 (GND), U2.47 (GND), U2.51 (GND), U2.60 (~PWREN), U3.5 (GND), Y3.2, Y3.4; also elsewhere on the board
unnamed: C53.1, C55.1, FB2.2, U2.9 (VPLL)
unnamed: C54.1, C57.1, FB3.2, U2.4 (VPHY)
unnamed: C56.1, U2.2 (OSCI), Y3.1
unnamed: C59.1, U2.3 (OSCO), Y3.3
unnamed: D3.2 (A), J7.A4 (VBUS), J7.A9 (VBUS), J7.B4 (VBUS), J7.B9 (VBUS)
unnamed: D4.1 (K), U2.30 (ACBUS4)
unnamed: D4.2 (A), R33.1
unnamed: D5.1 (K), U2.29 (ACBUS3)
unnamed: D5.2 (A), R34.2
unnamed: D6.1 (K), U2.55 (BCBUS4)
unnamed: D6.2 (A), R36.1
unnamed: D7.1 (K), U2.54 (BCBUS3)
unnamed: D7.2 (A), R35.1
unnamed: D9.2 (RK), R39.2
unnamed: D9.3 (GK), R40.2
unnamed: D9.4 (BK), R41.1
unnamed: J7.A5 (CC1), R32.1, TP7.1
unnamed: J7.B5 (CC2), R31.1, TP5.1
unnamed: Q3.3 (D), R39.1
unnamed: Q4.3 (D), R40.1
unnamed: Q5.3 (D), R41.2
unnamed: R23.2, U2.14 (~RESET)
unnamed: R24.1, U2.36 (~SUSPEND)
unnamed: R25.1, U3.6 (ORG)
unnamed: R26.2, R27.1, U3.4 (DO)
unnamed: R30.2, U2.6 (REF)
unnamed: R38.2, R46.2, SW2.1 (A)

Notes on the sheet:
User button
FT2232H EEPROM
User RGB led
Place near VCORE and VCIO
USB-C 2.0

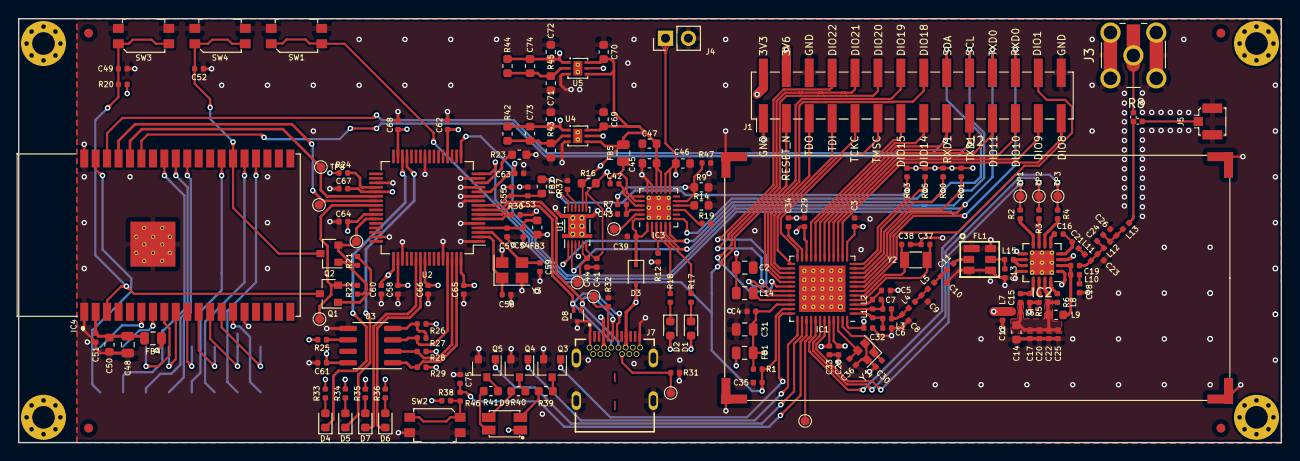
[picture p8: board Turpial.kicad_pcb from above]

Board: 4 copper layers, 140.0 x 47.0 mm, 197 parts (1 on the bottom side), 148 nets.
